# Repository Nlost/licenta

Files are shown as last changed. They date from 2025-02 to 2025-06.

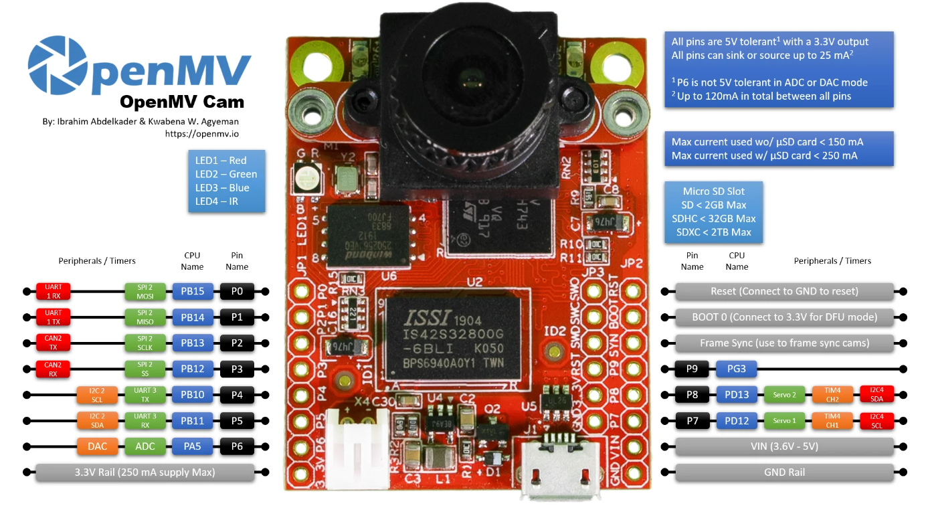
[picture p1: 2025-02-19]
doc/Pinout/OpenMV.png

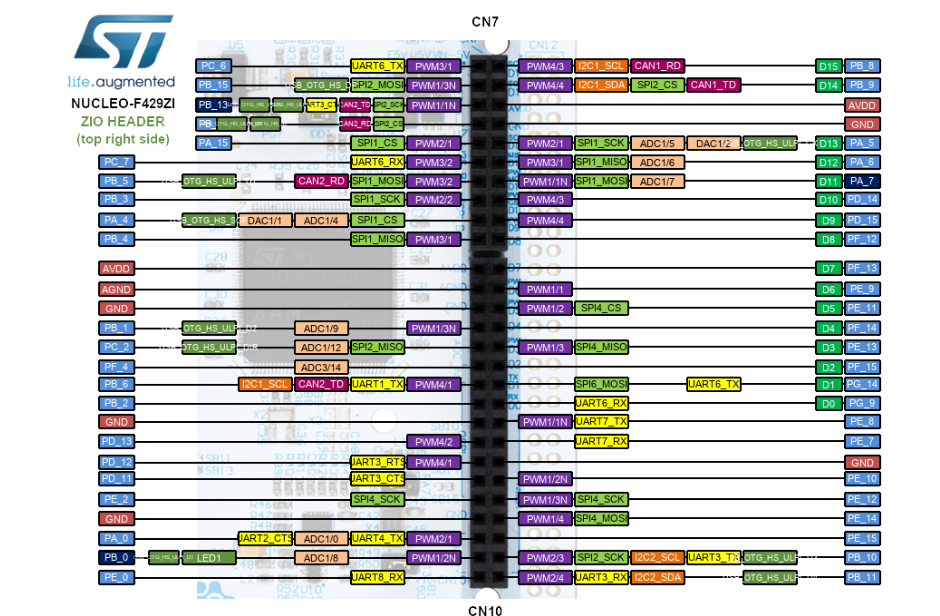
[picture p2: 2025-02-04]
doc/Pinout/ZIO HEADER (top right side).png

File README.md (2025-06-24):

Lucrare de licență cu tema "Robot mobil autonom pentru urmarirea unei persoane"
====
**Candidat: Dan BALAN**

**Coordonator științific: Ș.l.dr.ing. Ana Maria DAN**

Adresa de Github
-------

[Github repository](https://github.com/Nlost/licenta.git)

Structura proiectului
----

```bash
├── Dev      <- Proiectul STM32CubeIDE cu codul sursă pentru STM32F439ZI
├── doc      <- Documentații utilizate pentru dezvoltarea aplicației
├── models   <- Modelele 3D și desenele tehnice ale șasiului
├── openmv   <- Codul sursă pentru OpenMV Cam H7     
```
Pașii de compilare
-----

**Codul sursă pentru STM32**

1. Se descarcă aplicația [STM32CubeIDE](https://www.st.com/en/development-tools/stm32cubeide.html)
2. La pornirea aplicației, STM32CubeIDE va cere o cale pentru proiect. Se selectează folderul în care a fost descărcat repositoriul de Git.
3. Pentru a compila proiectul, navigați în bara de sus la secțiunea **”Project” -> ”Build all”** sau apăsați pe iconița cu imaginea unui ciocan.
4. Pentru a încărca codul, conectați plăcuța la un PC și navigați în bara de sus la secțiunea **”Run” -> ”Run”** sau apăsați pe iconița de culoare verde cu semnul Play pe ea. 

**Codul sursă pentru OpenMV Cam H7**

1. Se descarcă aplicația [OpenMV IDE](https://openmv.io/pages/download)
2. Se deschide fișierul **main.py** din folderul **openmv** folosind OpenMV IDE
3. Pentru a încărca fișierul main.py, conectați plăcuța la un PC și navigați în bara de sus la secțiunea **”Tools” -> ”Save open script to OpenMV Cam (as main.py)”**

*Observații: Codul poate fi încărcat pe plăcuță și fără utilizarea aplicației OpenMV IDE. Copierea fișierului main.py direct în sistemul de fișiere ale plăcuței OpenMV Cam H7 va duce la același rezultat ca și în pașii descriși mai sus.*

Pașii de lansare a proiectului
---
1. Se încarcă codul pe toate plăcuțele.
2. Se alimentează plăcuțele OpenMV Cam H7 și STM32 Nucleo-144 prin portul micro USB conectat la un powerbank.
3. Se alimentează driverele de motoare de la o sursă de 12V.

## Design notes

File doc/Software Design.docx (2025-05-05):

# Project Architecture

OpenMV Cam 2

- Folosind algoritmii de Machine Learning, detectează o față și trimite datele despre persoană la STM32.
- Trimite snapshot de video la STM32

UART3 (Plan B)

PWM

Wi-Fi

PC

- Afișează video

PWM

Motoare

Motor Driver (L239D)

- Controlează motoarele

UART3

Esp32

- Primește datele de la STM32 și le trimite prin Wi-Fi la un laptop
- Primește date despre camera selectată care să transmită video (snapshoturi de poze)

STM32F439ZI

- Primește și procesează datele de la OpenMV H7 Cam (2x)
- Ia deciziile de mișcare a roților și comunica cu driver-ul L239D
- (?) Primește snapshot-uri de video de la cameră, o criptează și o trimite la ESP32

UART2

UART1

SPI

OpenMV Cam 1

- Folosind algoritmii de Machine Learning, detectează o față și trimite datele despre persoană la STM32.
- Trimite snapshot de video la STM32
- (?) Cryptează snapshot-ul și le trimite direct la ESP32

# Planificare

Titlu | Status | Estimat (zile) | Prioritate
[ESP32] Configure UART | Backlog | 7 | Plan A extended
[PC] Create PC application showing video | Backlog | 10 | Plan A extended
[ESP32] Configure Wi-fi | Backlog | 7 | Plan A extended
[OpenMV] UART Integration | Ready | 7 | Plan A extended
[OpenMV] Activate Machine Learning | Ready | 5 | Plan A
[STM32] Create Motor Driver code | Ready | 3 | Plan A
[OpenMV] Configuration of SPI | In progress | 7 | Plan A
[Hardware] Assemble the robot | In progress | 3 | Plan A
[STM32] UART Integration | In review | 3 | Plan A
[Hardware] Make the 3D model of the Robot | Done | | Plan A
[STM32] SPI configuration | Done | | Plan A
[STM32] Crypto understasting | Done | | Plan A
[STM32] Integrate AES GCM alghoritm | Done | | Plan A
[STM32] Configure PWM | Done | | Plan A

Soluții existente:

https://www.instructables.com/Object-Finding-Personal-Assistant-Robot-Ft-Raspber/

https://www.theverge.com/2021/9/22/22685649/gita-gitamini-cargo-carrying-robot-piaggio

https://techxplore.com/news/2023-12-robots-re-identify-human-users.html

https://circuitdigest.com/microcontroller-projects/human-following-robot-using-arduino-and-ultrasonic-sensor

https://www.instructables.com/Object-Finding-Personal-Assistant-Robot-Ft-Raspber/

Documentații:

https://www.st.com/en/microcontrollers-microprocessors/stm32f439zi.html

https://openmv.io/products/openmv-cam-h7-plus

https://eu.mouser.com/datasheet/2/389/l293d-1849134.pdf

Soluții existente

# Software Design for STM32

Esp32

In process

Aes_encrypt

Crypto (HAL)

OpenMV_SPI_MainFunction()

OpenMV_UART_MainFunction()

MotDrv

- MotDrv_GoFront()
- MotDrv_GoBack()
- MotDrv_TurnRight()
- MotDrv_TurnLeft()
- MotDrv_Stay()

MotDrv_TakeDecision()

Openmv

- OpenMV_SPI_ReadWrite()
- OpenMV_UART_ReceivePhoto()

Main

- Inits all modules (SPI, UART, Crypto, PWM…)
- Calls API`s for modules

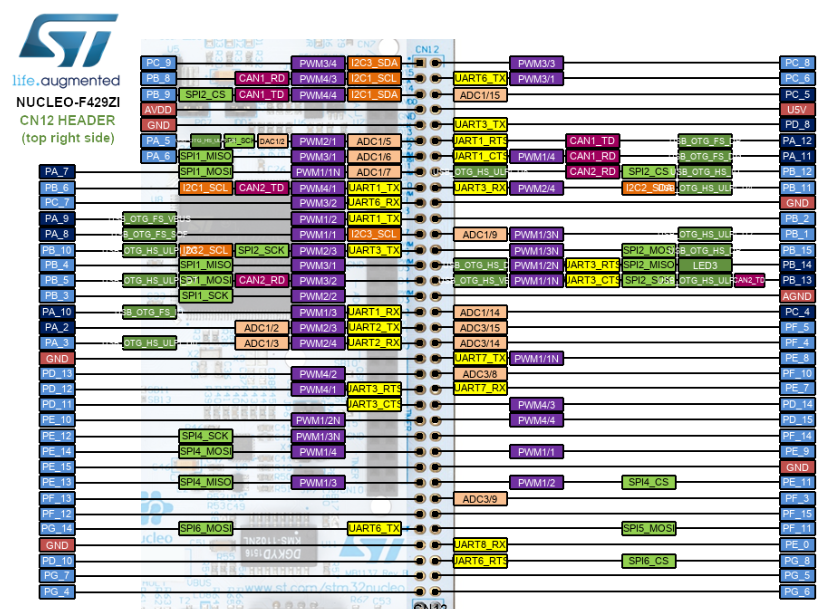
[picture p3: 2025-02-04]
doc/Pinout/CN12 HEADER (top right side).png

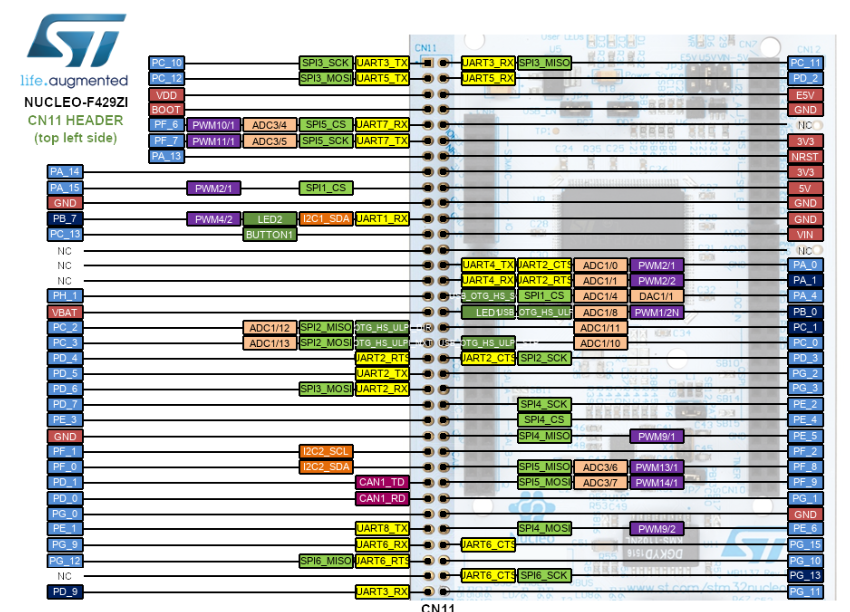
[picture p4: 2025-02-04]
doc/Pinout/CN11 HEADER (top left side).png

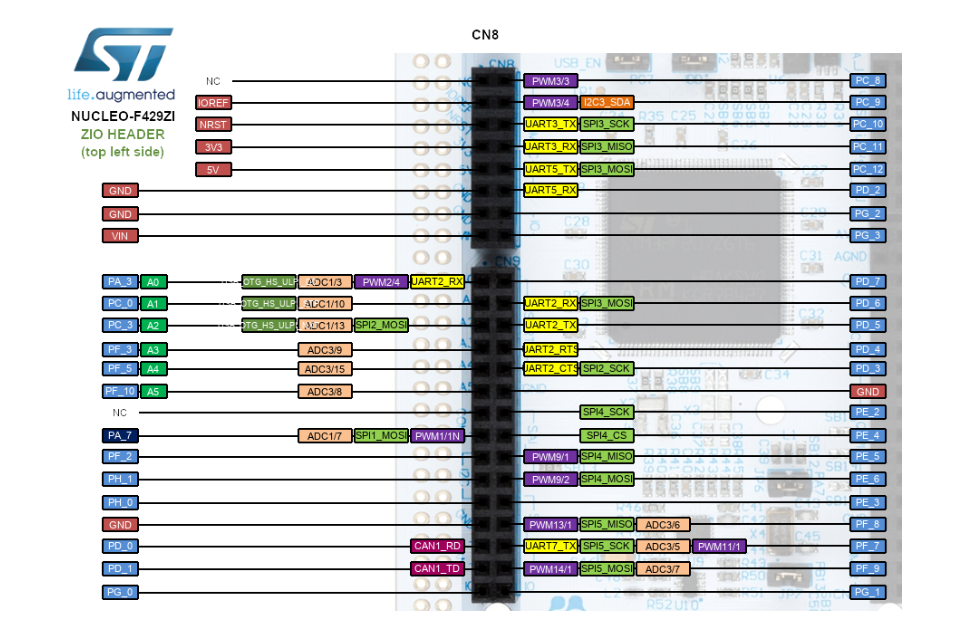
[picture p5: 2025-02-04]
doc/Pinout/ZIO HEADER (top left side).png

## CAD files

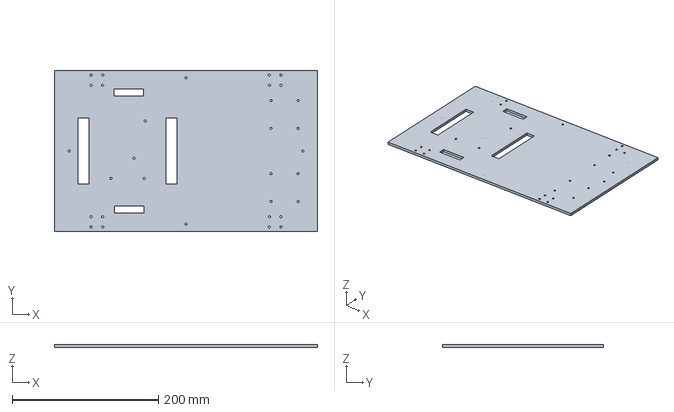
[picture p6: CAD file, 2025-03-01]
models/Sasi robot.FCStd
360.0 x 220.0 x 4.00 mm

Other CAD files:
models/Sasi_robot_sus.stl
models/Sasi robot_jos.stl
models/Sasi robot2.FCStd

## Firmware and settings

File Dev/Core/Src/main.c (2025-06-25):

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
/* Includes ------------------------------------------------------------------*/
#include "main.h"

SPI_HandleTypeDef hspi4;
DMA_HandleTypeDef hdma_spi4_rx;
DMA_HandleTypeDef hdma_spi4_tx;

TIM_HandleTypeDef htim4;

UART_HandleTypeDef huart4;
UART_HandleTypeDef huart5;
UART_HandleTypeDef huart7;
DMA_HandleTypeDef hdma_uart4_rx;
DMA_HandleTypeDef hdma_uart5_rx;
DMA_HandleTypeDef hdma_uart7_tx;

void SystemClock_Config(void);
static void MX_GPIO_Init(void);
static void MX_DMA_Init(void);
static void MX_UART4_Init(void);
static void MX_UART5_Init(void);
static void MX_UART7_Init(void);
static void MX_TIM4_Init(void);
static void MX_SPI4_Init(void);
/**
  * @brief  The application entry point.
  * @retval int
  */
int main(void)
{

  /* USER CODE BEGIN 1 */
	//HAL_StatusTypeDef retVal = HAL_OK;
  /* USER CODE END 1 */

  /* MCU Configuration--------------------------------------------------------*/

  /* Reset of all peripherals, Initializes the Flash interface and the Systick. */
  HAL_Init();

  /* Configure the system clock */
  SystemClock_Config();

  /* Initialize all configured peripherals */
  MX_GPIO_Init();
  MX_DMA_Init();
  MX_UART4_Init();
  MX_UART5_Init();
  MX_UART7_Init();
  MX_TIM4_Init();
  MX_SPI4_Init();
  /* USER CODE BEGIN 2 */
  OpenMV_Init();


  /* USER CODE END 2 */

  /* Infinite loop */
  /* USER CODE BEGIN WHILE */
  while (1)
  {
    /* USER CODE END WHILE */

    /* USER CODE BEGIN 3 */
	  HAL_GPIO_TogglePin(GPIOB, LD3_Pin);
	  OpenMV_SPI_MainFunction(&hspi4);
	  MotDrv_TakeDecision(cameraData1, cameraData2);
  }
  /* USER CODE END 3 */
}

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
/* USER CODE BEGIN 4 */
int _write(int file, char *ptr, int len)
{
  (void)file;
  int DataIdx;

  for (DataIdx = 0; DataIdx < len; DataIdx++)
  {
    ITM_SendChar(*ptr++);
  }
  return len;
}




/* USER CODE END 4 */
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


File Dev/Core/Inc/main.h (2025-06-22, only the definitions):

#define SPI1_NSS2_Pin GPIO_PIN_3
#define SPI1_NSS2_GPIO_Port GPIOE
#define SPI1_NSS1_Pin GPIO_PIN_4
#define SPI1_NSS1_GPIO_Port GPIOE
#define USER_Btn_Pin GPIO_PIN_13
#define USER_Btn_GPIO_Port GPIOC
#define FrontRight_Con1_Pin GPIO_PIN_4
#define FrontRight_Con1_GPIO_Port GPIOA
#define FrontRight_Con2_Pin GPIO_PIN_5
#define FrontRight_Con2_GPIO_Port GPIOA
#define BackRight_Con1_Pin GPIO_PIN_6
#define BackRight_Con1_GPIO_Port GPIOA
#define BackRight_Con2_Pin GPIO_PIN_7
#define BackRight_Con2_GPIO_Port GPIOA
#define LD3_Pin GPIO_PIN_14
#define LD3_GPIO_Port GPIOB
#define USB_PowerSwitchOn_Pin GPIO_PIN_6
#define USB_PowerSwitchOn_GPIO_Port GPIOG
#define USB_OverCurrent_Pin GPIO_PIN_7
#define USB_OverCurrent_GPIO_Port GPIOG
#define FrontLeft_Con1_Pin GPIO_PIN_6
#define FrontLeft_Con1_GPIO_Port GPIOC
#define FrontLeft_Con2_Pin GPIO_PIN_7
#define FrontLeft_Con2_GPIO_Port GPIOC
#define BackLeft_Con1_Pin GPIO_PIN_8
#define BackLeft_Con1_GPIO_Port GPIOC
#define BackLeft_Con2_Pin GPIO_PIN_9
#define BackLeft_Con2_GPIO_Port GPIOC
#define TMS_Pin GPIO_PIN_13
#define TMS_GPIO_Port GPIOA
#define TCK_Pin GPIO_PIN_14
#define TCK_GPIO_Port GPIOA
#define LD2_Pin GPIO_PIN_7
#define LD2_GPIO_Port GPIOB
#define AES128_KeyLength 128
#define AES128_IVLength 128

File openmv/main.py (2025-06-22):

import sensor
import time
import image
import pyb
from machine import LED

led = LED("LED_RED")

class spi_slave:
    def __init__(self, cs_pin="P3", clk_polarity=1, clk_phase=0, spi_bus=2):  # private
        import pyb
        self.__pin = pyb.Pin(cs_pin, pyb.Pin.IN)
        self.__polarity = clk_polarity
        self.__clk_phase = clk_phase
        self._put_short_timeout_reset = 50
        self.__spi = pyb.SPI(spi_bus)

    def put_bytes(self, data, timeout_ms):  # protected
        import pyb
        start = pyb.millis()
        while self.__pin.value():
            if pyb.elapsed_millis(start) >= self._put_short_timeout_reset:
                return
        self.__spi.init(pyb.SPI.SLAVE, polarity=self.__polarity, phase=self.__clk_phase)
        try:
            self.__spi.send(data, timeout=timeout_ms)
        except OSError:
            pass
        self.__spi.deinit()

# Initialize the sensor
sensor.reset()
sensor.set_contrast(3)
sensor.set_auto_gain(True)      # Enable automatic gain
sensor.set_auto_exposure(True)  # Enable automatic exposure
sensor.set_gainceiling(16)
sensor.set_framesize(sensor.VGA)
sensor.set_pixformat(sensor.GRAYSCALE)
face_cascade = image.HaarCascade("frontalface", stages=25)
clock = time.clock()

# SPI Slave interface
interface = spi_slave(cs_pin="P3", clk_polarity=1, clk_phase=0, spi_bus=2)

# Shared state
ready_to_send = False
send_buffer = bytearray(7)

# Interrupt sets the flag
def nss_callback(line):
    global ready_to_send
    ready_to_send = True

pyb.ExtInt(pyb.Pin("P3"), pyb.ExtInt.IRQ_FALLING, pyb.Pin.PULL_UP, nss_callback)

# Main loop
while True:
    clock.tick()
    img = sensor.snapshot()

    # Detect faces
    objects = img.find_features(face_cascade, threshold=0.75, scale_factor=1.25)
    for r in objects:
        img.draw_rectangle(r)

    # Example data packing based on face count
    num_faces = min(len(objects), 255)
    if(num_faces == 1): #Data frame
        led.toggle()
        x = objects[0][0]
        y = objects[0][1]
        h = objects[0][2]
        send_buffer[0] = 85 # Header byte
        send_buffer[1] = x & 0xFF
        send_buffer[2] = (x >> 8) & 0xFF
        send_buffer[3] = y & 0xFF
        send_buffer[4] = (y >> 8) & 0xFF
        send_buffer[5] = h & 0xFF
        send_buffer[6] = (h >> 8) & 0xFF
    else: #Error frame
        send_buffer[0] = 86  # Header byte
        send_buffer[1] = 0xAA
        send_buffer[2] = 0xFF  
        send_buffer[3] = 0x10
        send_buffer[4] = 0xAA
        send_buffer[5] = 0xFF
        send_buffer[6] = 0x10
    # SPI send logic (non-blocking during interrupt)
    if ready_to_send:
        try:
            interface.put_bytes(send_buffer, 1000)
        except Exception as e:
            continue
        ready_to_send = False

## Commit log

2025-02-19 Added OpenMV Driver
2025-02-19 [STM32]OpenMV Driver update
2025-02-20 Modified openmv driver
2025-02-23 [OpenMV] Integrated SPI
2025-02-23 [STM32] Integrated SPI
2025-02-23 [OpenMV] SPI Changes
2025-02-26 [OpenMV] Configuration of SPI
2025-02-26 [STM32] Configuration of SPI
2025-03-01 Add 3D models for robot
    [Sasi robot.FCStd, Sasi robot2.FCStd, Sasi robot_jos.stl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]
2025-03-01 Added UART and Crypto
2025-03-14 Added PWM
2025-05-05 SPI STM32 and OpenMV configured
2025-05-20 SPI sending 16 bit and robot going front and back as expected

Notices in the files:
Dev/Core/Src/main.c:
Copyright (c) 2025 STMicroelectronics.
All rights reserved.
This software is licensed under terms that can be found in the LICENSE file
